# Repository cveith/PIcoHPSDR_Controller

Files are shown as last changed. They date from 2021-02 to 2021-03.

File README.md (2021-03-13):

# PIcoHPSDR Controller

A hardware controller for the piHPSDR application by John Melton, G0ORX.
I've called it PIcoHPSDR Controller, as it's using the newly released Raspberry Pi Pico as an abstraction layer to the hardware.

Inspired by the original controller and therefore parts of this work is based on the original PiHPSDR Controller designed by Kjell Karlsen, LA2NI, et al.
Many thanks Kjell.

## Features
- 1 VFO encoder (5V, open collector outputs)
- 4 Dual Shaft encoders (Alps EC11E type)
- 16 Push Buttons
- PTT, Up, Down, FST Scan from the MH31-A8J microphone
- External PTT, for foot switch
- CW Paddle input
- Audio Out via Headphone or Speaker Output
- Audio In via MH31-A8J Microphone from Yaesu

For more details on piHPSDR, please see https://github.com/g0orx/pihpsdr.

## Protocol Details
The data transmission protocol is pretty straight forward.
Each control element has it's own 7-bit address from Bit 1 through 7.
Bit 0 is reserved for the data portion.

Rotary encoder moves are indicated with value 0 for a counterclockwise step and 1 for a clockwise step.

### Example
PC receives 0b00000010 (Addr: 1, Data: 0):
The main VFO encoder has been turned ccw.

PC receives 0b00000100 (Addr: 2, Data: 1):
The encoder 2 has been turned clock wise.

PC receives 0b00010110 (Addr: 11, Data: 1):
The Encoder 2 Button has been pressed.

PC receives 0b00010110 (Addr: 11, Data: 0):
Encoder 2 Button has been released.

The release state is not used for most switches, but necessary for the external PTT and the Microphone PTT button.

The firmware is split of on a separate repository. Please see https://github.com/cveith/PIcoHPSDR_Controller_Firmware.
Detailed address informations are in a Openoffice Calc file as well.

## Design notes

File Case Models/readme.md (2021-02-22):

# PIcoHPSDR Controller Case Assembly

## Needed Parts

200mm long DSI Connector Cable for connection Pi TFT and Raspberry PI.
3D Printed VFO Dial
17 3d Printed Button Knobs
4 3D printed upper encoder knobs
4 3D printed lower encoder knobs
2 Speakers (CMS-402811-28SP from CUI Devices)

## Two Case models

First Case model uses extruded aluminium profiles as upper and lower case parts.

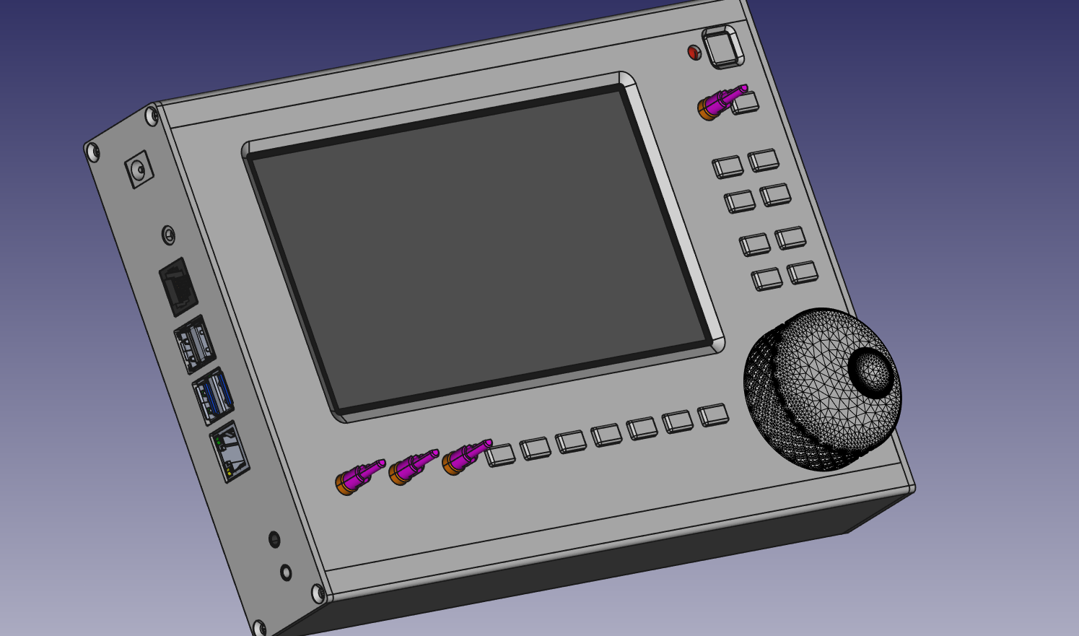
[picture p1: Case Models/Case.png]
Case 1 image


Second model uses bend metal sheets as front and back panel.
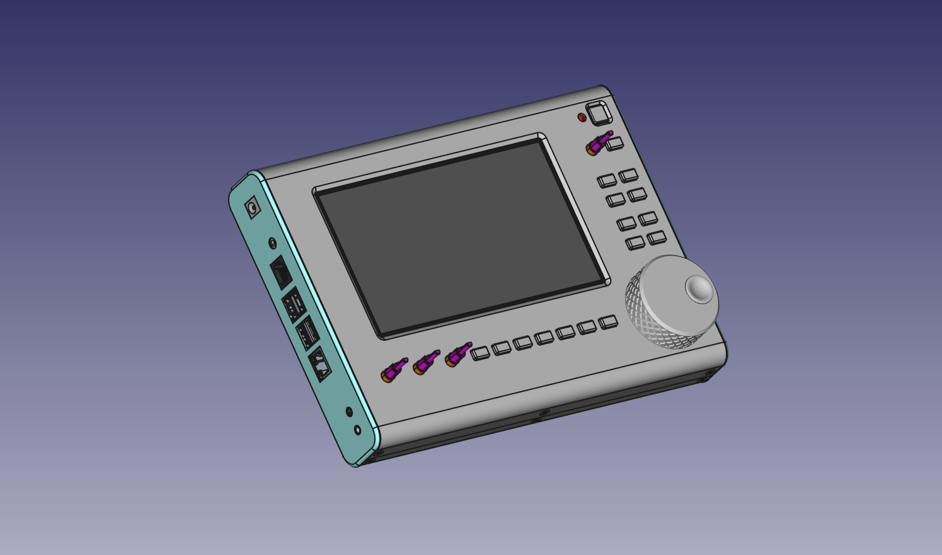
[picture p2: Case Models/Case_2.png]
Case 2 image


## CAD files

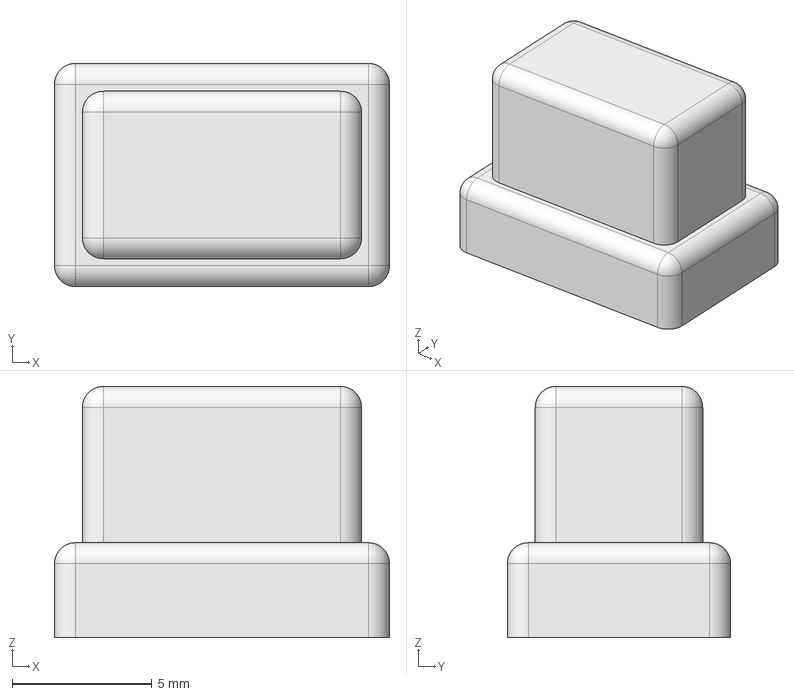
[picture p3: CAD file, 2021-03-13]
Case Models/Button_Cap.FCStd
12.0 x 8.00 x 9.00 mm

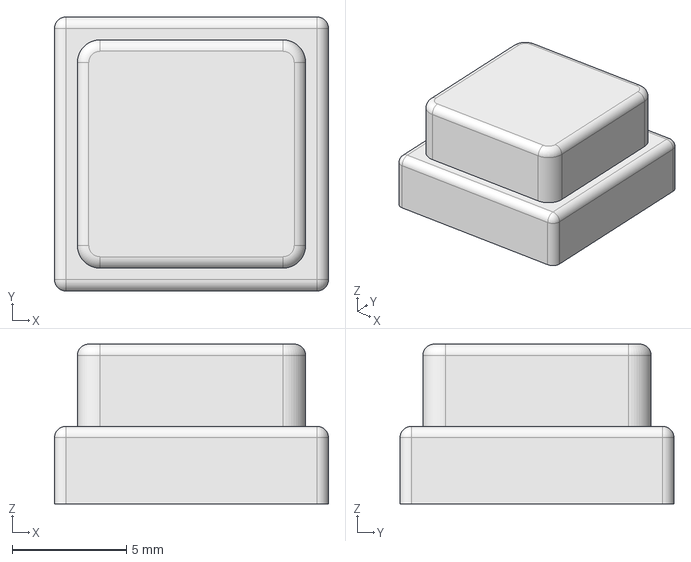
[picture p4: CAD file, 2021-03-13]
Case Models/Button_Cap_Power.FCStd
12.0 x 12.0 x 7.00 mm

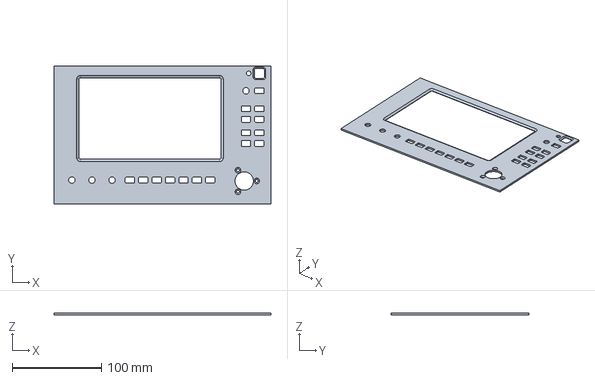
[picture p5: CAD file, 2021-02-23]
Case Models/Front for bent metal sheet.stp
243.0 x 155.0 x 2.00 mm

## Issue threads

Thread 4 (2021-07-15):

Audio Circuit not working

cveith, 2021-07-15:
The audio circuit needs a redesign.
It's only powered from the pi's 3.3V rail which doesn't provide enough power to drive the audio Circuit.

The driver support for that codec is limited.

A Re-Design will take place in the next versions. Propably contain a more "HiFiBerry" compatible solution would be great.

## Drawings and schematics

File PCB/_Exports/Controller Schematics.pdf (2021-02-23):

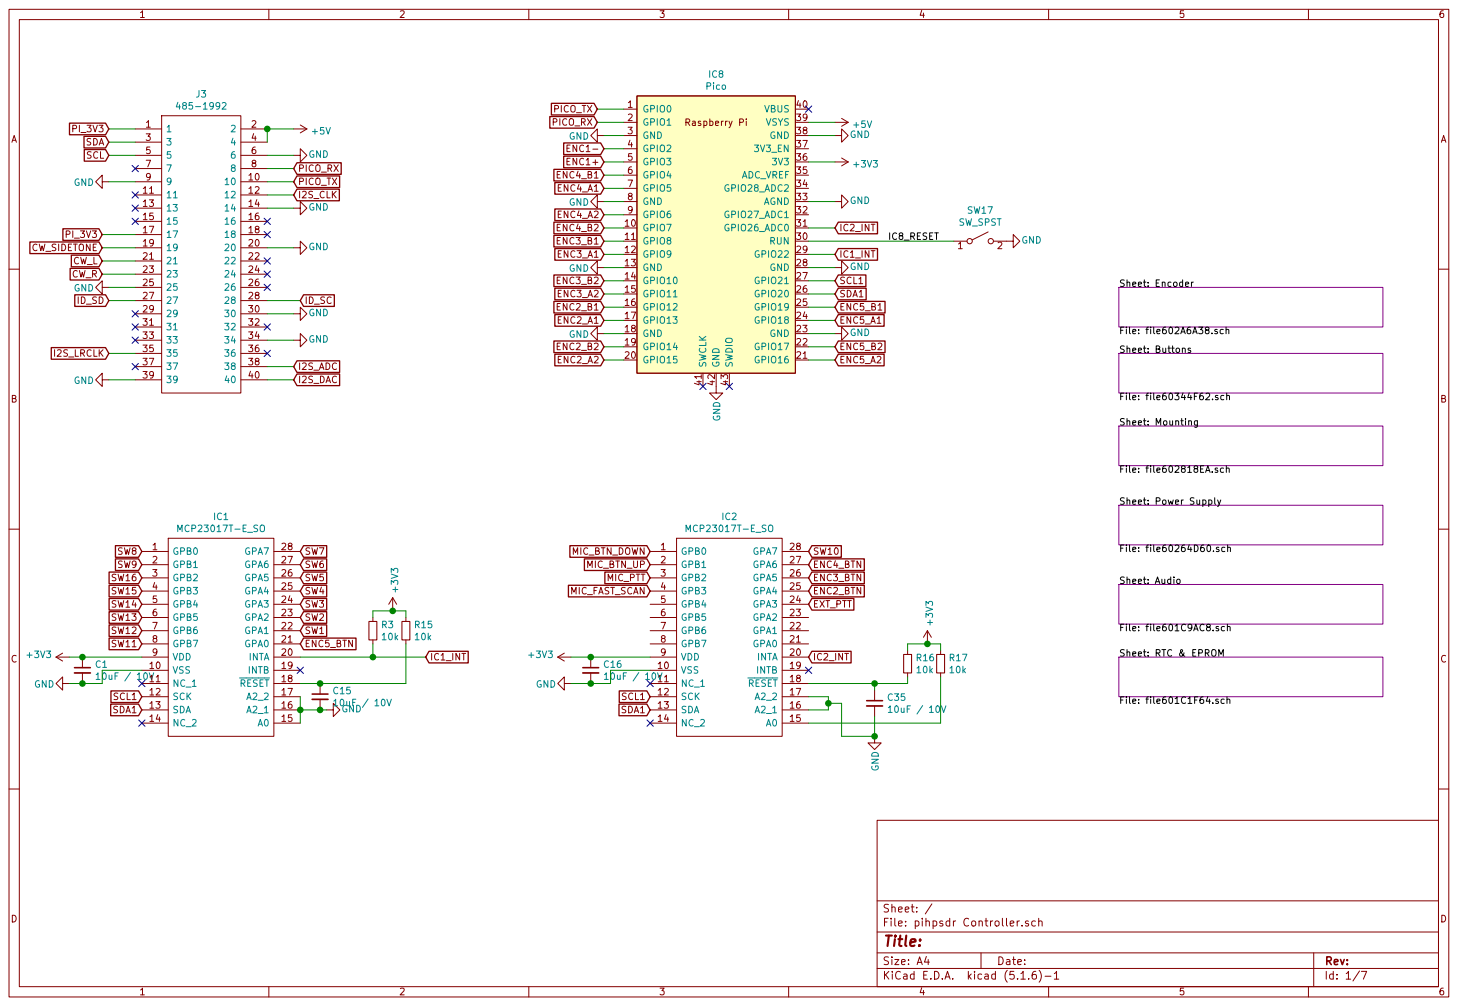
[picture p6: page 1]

Sheet: Encoder File: file602A6A38.sch Sheet: Buttons File: file60344F62.sch Sheet: RTC & EPROM

File: file601C1F64.sch Sheet: Audio File: file601C9AC8.sch Sheet: Mounting File: file602818EA.sch Sheet: Power Supply File: file60264D60.sch C1

File: pihpsdr Controller.sch Sheet: /
Id: 1/7 Title:

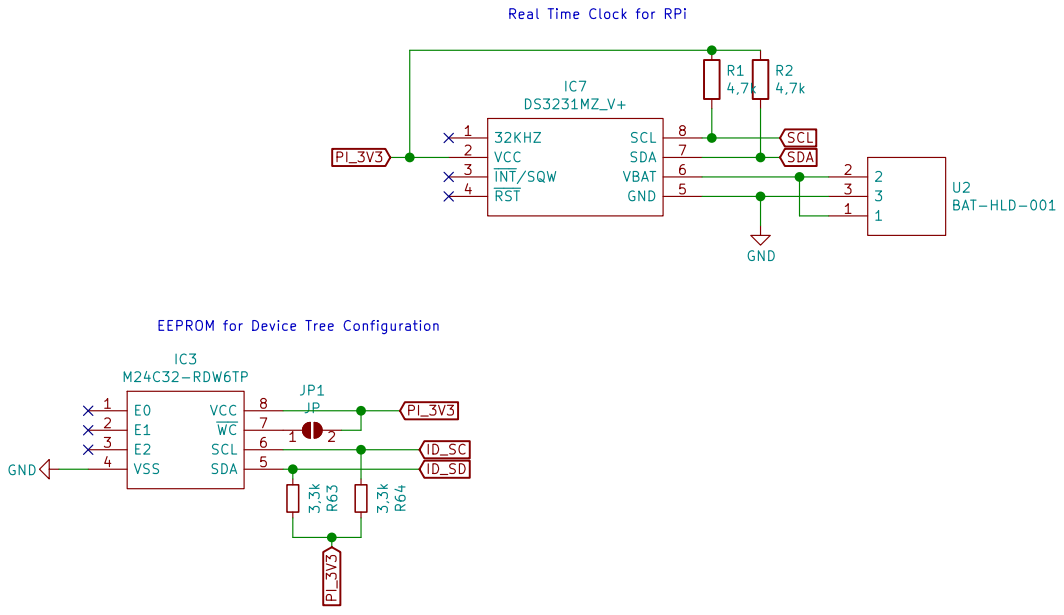
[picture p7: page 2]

Id: 2/7 Title: File: file601C1F64.sch Sheet: /RTC & EPROM/ 3,3k R63

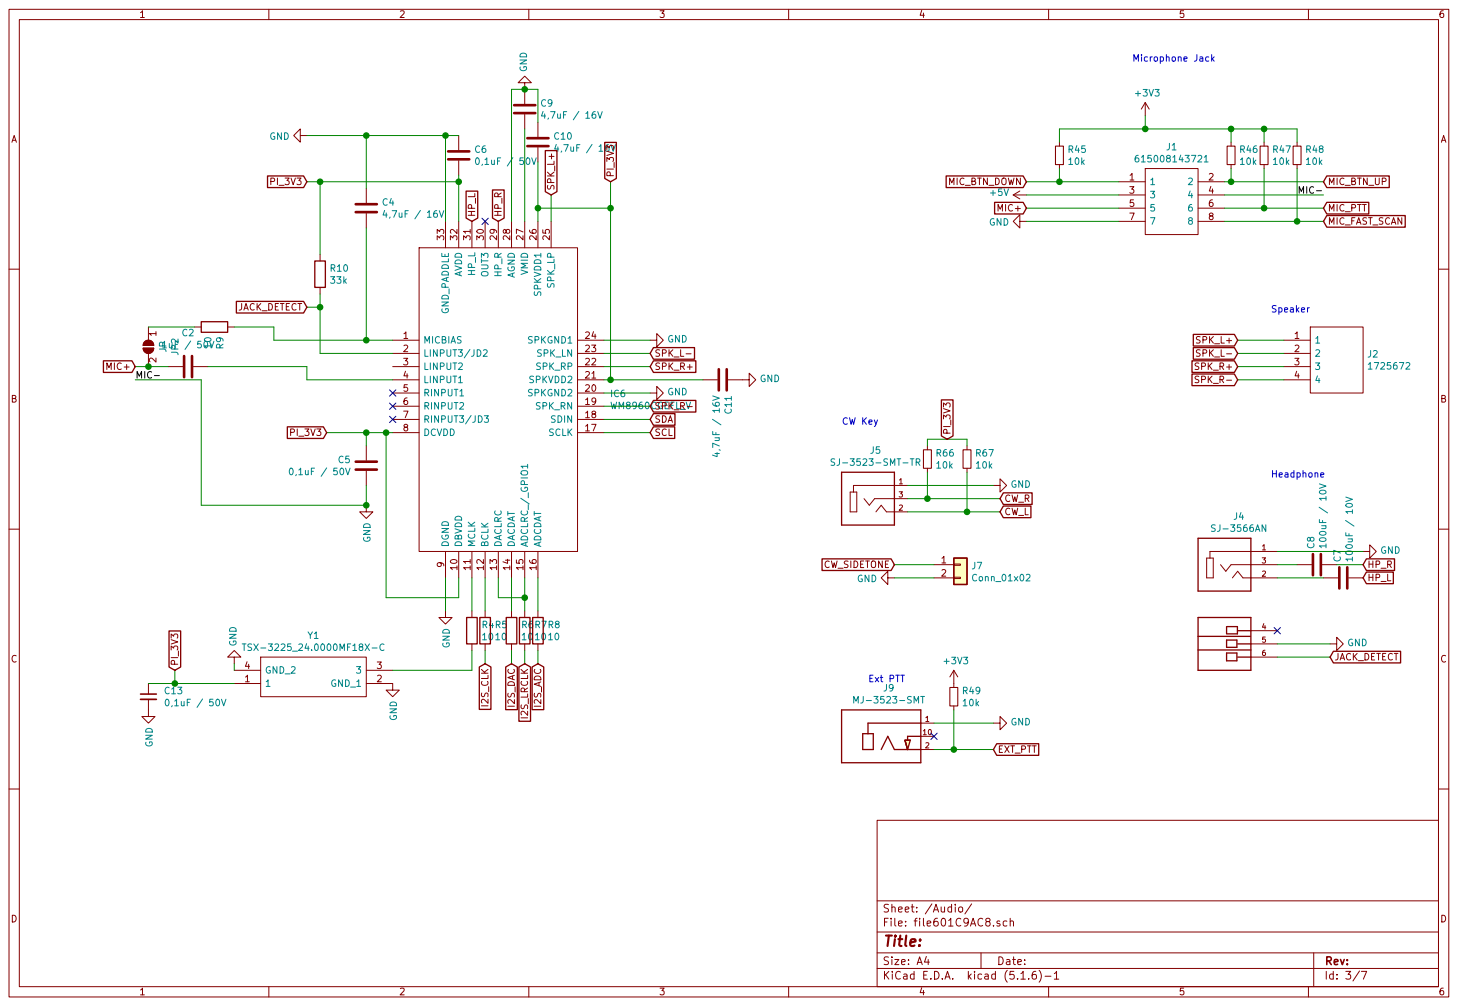
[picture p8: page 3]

Id: 3/7 Title: File: file601C9AC8.sch Sheet: /Audio/ R66

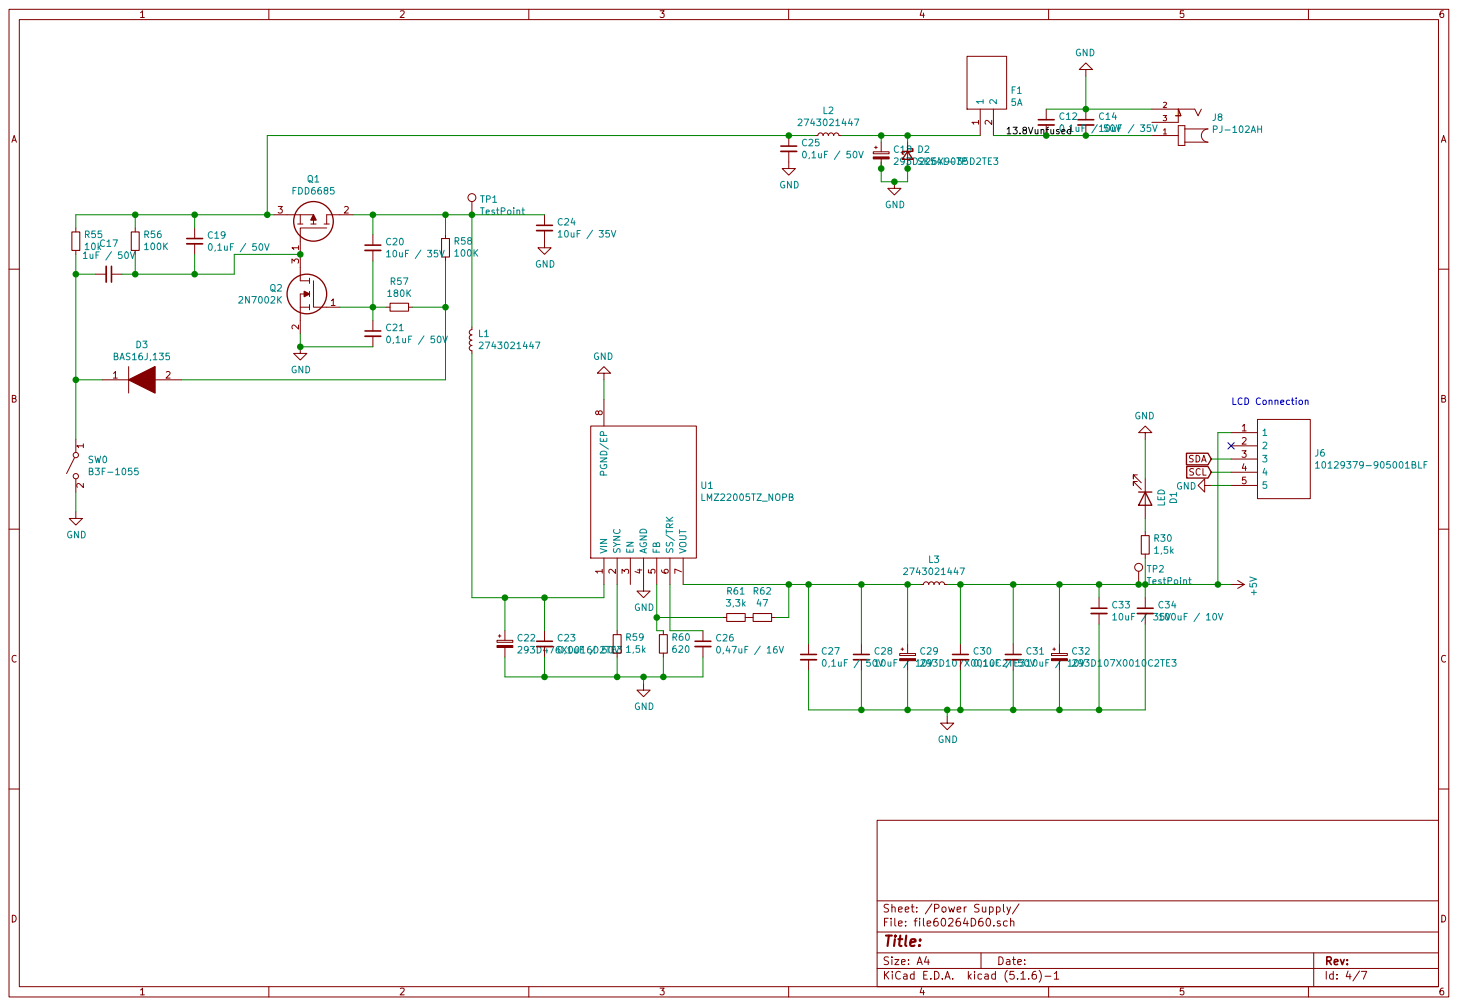
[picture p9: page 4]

Id: 4/7 Title: File: file60264D60.sch Sheet: /Power Supply/ R61

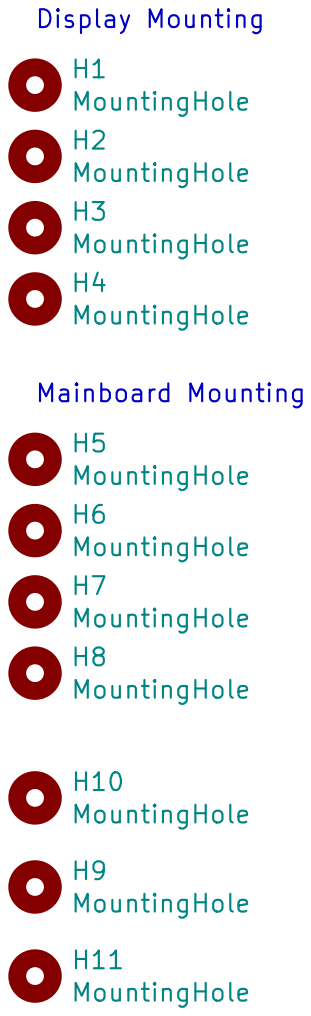
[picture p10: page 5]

Id: 5/7 Title: File: file602818EA.sch Sheet: /Mounting/

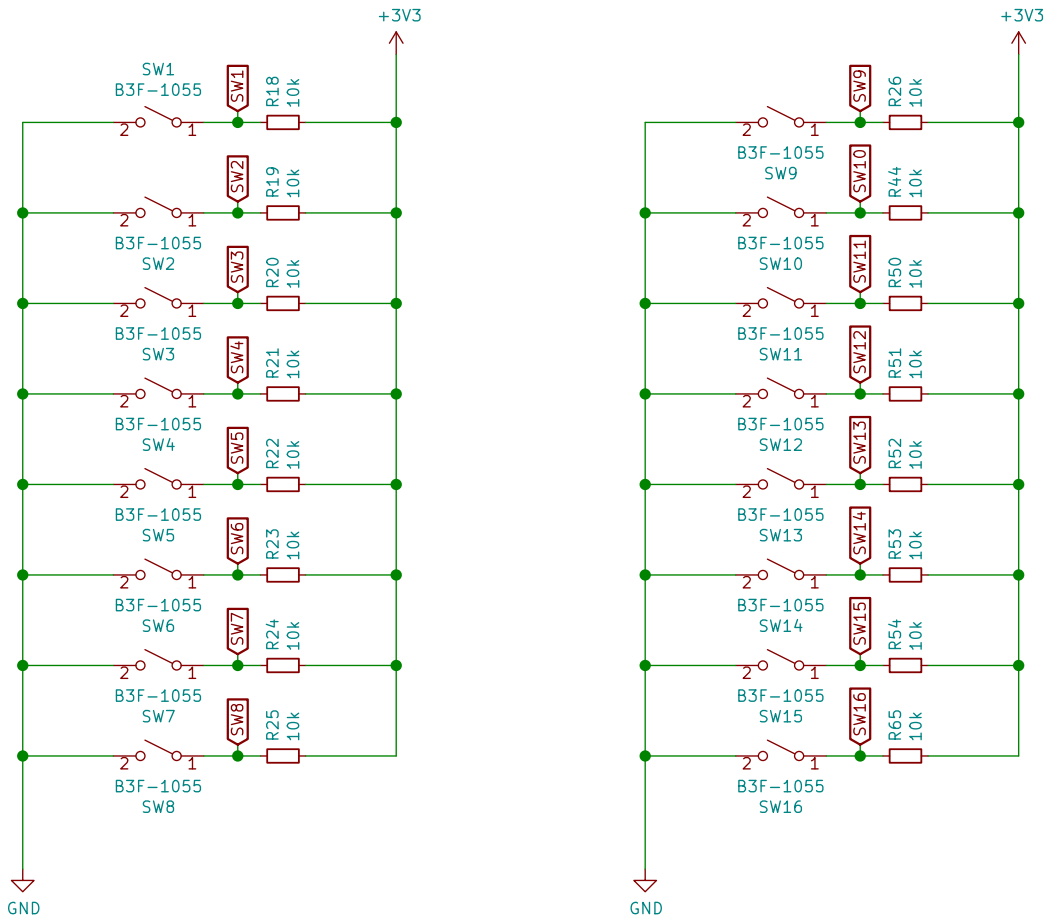
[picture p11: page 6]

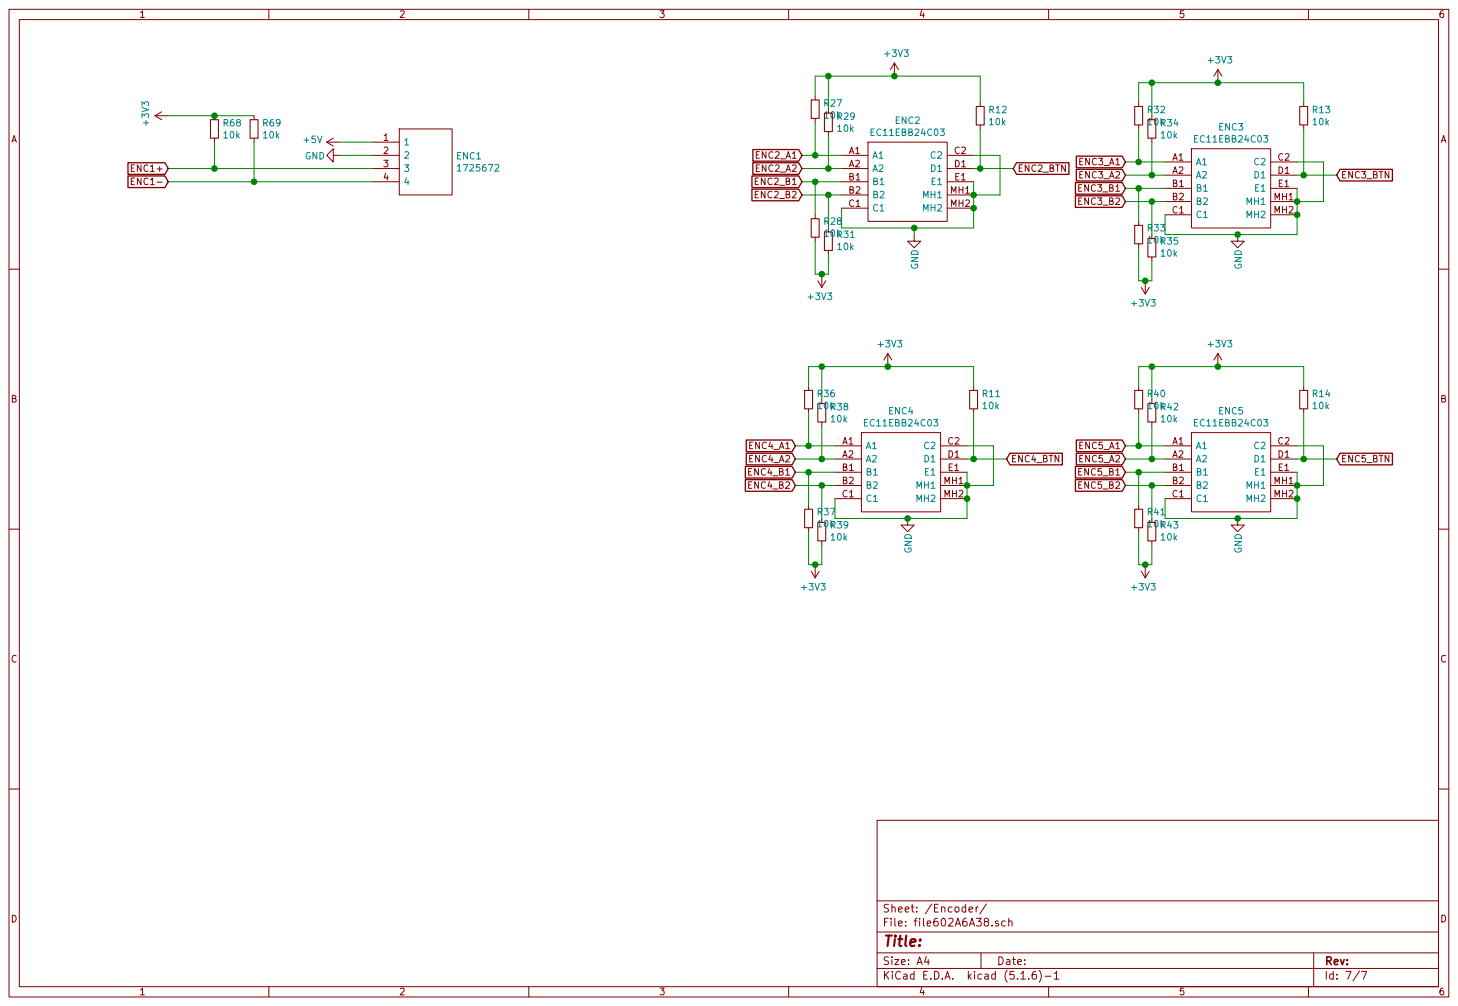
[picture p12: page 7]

Id: 7/7 Title: File: file602A6A38.sch Sheet: /Encoder/

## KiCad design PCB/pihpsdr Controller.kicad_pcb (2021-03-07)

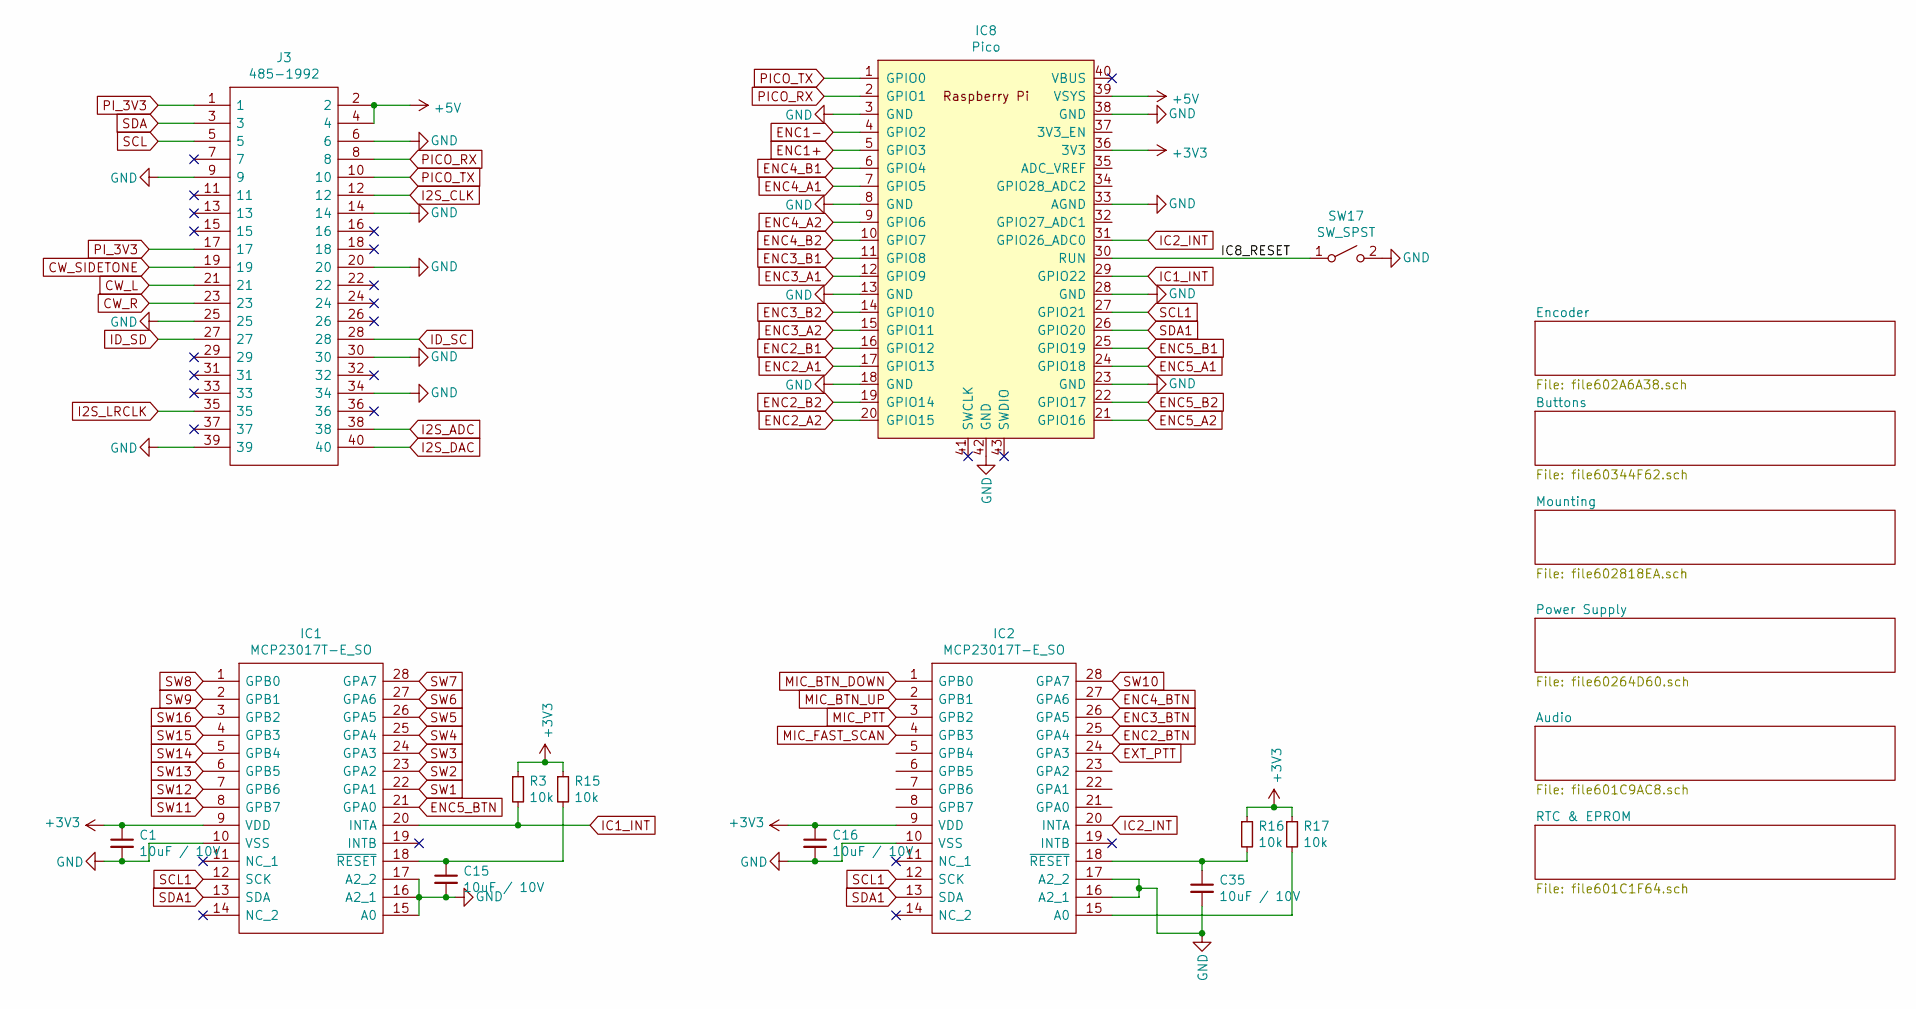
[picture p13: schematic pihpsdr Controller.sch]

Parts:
C1, C15, C16, C35: 10uF / 10V; C_0805_2012Metric_Pad1.15x1.40mm_HandSolder; Manufacturer_Part_Number CL21A106MPFNNNE; LCSC C15850
IC1, IC2: MCP23017T-E_SO; SOIC127P1030X265-28N; Mouser Part Number 579-MCP23017T-E/SO
IC8: Pico; RPi_Pico_SMD_TH; Mouser Part Number 474-DEV-17829
J3: 485-1992; 15445840_PI; Mouser Part Number 485-1992
R3: 10k; R_0805_2012Metric_Pad1.15x1.40mm_HandSolder; Mouser Part Number 71-CRCW080510K0FKEAC
R15, R16, R17: 10k; R_0805_2012Metric_Pad1.15x1.40mm_HandSolder; Manufacturer_Part_Number CRCW080510K0FKEAC; LCSC C17414
SW17: SW_SPST; TL3301SPF260QG; Manufacturer_Part_Number TL3301AF160QG; LCSC C273519

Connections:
+3V3: C1.1, C16.1, IC1.9 (VDD), IC2.9 (VDD), IC8.36 (3V3), R3.1, R15.1, R16.1, R17.1; also elsewhere on the board
+5V: IC8.39 (VSYS), J3.2, J3.4; also elsewhere on the board
/IC8_RESET: IC8.30 (RUN), SW17.1 (A)
CW_L: J3.21; also elsewhere on the board
CW_R: J3.23; also elsewhere on the board
CW_SIDETONE: J3.19; also elsewhere on the board
ENC1+: IC8.5 (GPIO3); also elsewhere on the board
ENC1-: IC8.4 (GPIO2); also elsewhere on the board
ENC2_A1: IC8.17 (GPIO13); also elsewhere on the board
ENC2_A2: IC8.20 (GPIO15); also elsewhere on the board
ENC2_B1: IC8.16 (GPIO12); also elsewhere on the board
ENC2_B2: IC8.19 (GPIO14); also elsewhere on the board
ENC2_BTN: IC2.25 (GPA4); also elsewhere on the board
ENC3_A1: IC8.12 (GPIO9); also elsewhere on the board
ENC3_A2: IC8.15 (GPIO11); also elsewhere on the board
ENC3_B1: IC8.11 (GPIO8); also elsewhere on the board
ENC3_B2: IC8.14 (GPIO10); also elsewhere on the board
ENC3_BTN: IC2.26 (GPA5); also elsewhere on the board
ENC4_A1: IC8.7 (GPIO5); also elsewhere on the board
ENC4_A2: IC8.9 (GPIO6); also elsewhere on the board
ENC4_B1: IC8.6 (GPIO4); also elsewhere on the board
ENC4_B2: IC8.10 (GPIO7); also elsewhere on the board
ENC4_BTN: IC2.27 (GPA6); also elsewhere on the board
ENC5_A1: IC8.24 (GPIO18); also elsewhere on the board
ENC5_A2: IC8.21 (GPIO16); also elsewhere on the board
ENC5_B1: IC8.25 (GPIO19); also elsewhere on the board
ENC5_B2: IC8.22 (GPIO17); also elsewhere on the board
ENC5_BTN: IC1.21 (GPA0); also elsewhere on the board
EXT_PTT: IC2.24 (GPA3); also elsewhere on the board
GND: C1.2, C15.2, C16.2, C35.2, IC1.10 (VSS), IC1.15 (A0), IC1.16 (A2_1), IC1.17 (A2_2), IC2.10 (VSS), IC2.16 (A2_1), IC2.17 (A2_2), IC8.3 (GND), IC8.8 (GND), IC8.13 (GND), IC8.18 (GND), IC8.23 (GND), IC8.28 (GND), IC8.33 (AGND), IC8.38 (GND), IC8.42 (GND), J3.6, J3.9, J3.14, J3.20, J3.25, J3.30, J3.34, J3.39, SW17.2 (B); also elsewhere on the board
I2S_ADC: J3.38; also elsewhere on the board
I2S_CLK: J3.12; also elsewhere on the board
I2S_DAC: J3.40; also elsewhere on the board
I2S_LRCLK: J3.35; also elsewhere on the board
IC1_INT: IC1.20 (INTA), IC8.29 (GPIO22), R3.2
IC2_INT: IC2.20 (INTA), IC8.31 (GPIO26_ADC0)
ID_SC: J3.28; also elsewhere on the board
ID_SD: J3.27; also elsewhere on the board
MIC_BTN_DOWN: IC2.1 (GPB0); also elsewhere on the board
MIC_BTN_UP: IC2.2 (GPB1); also elsewhere on the board
MIC_FAST_SCAN: IC2.4 (GPB3); also elsewhere on the board
MIC_PTT: IC2.3 (GPB2); also elsewhere on the board
unnamed: C15.1, IC1.18 (~RESET), R15.2
unnamed: C35.1, IC2.18 (~RESET), R16.2
unnamed: IC2.15 (A0), R17.2
PICO_RX: IC8.2 (GPIO1), J3.8
PICO_TX: IC8.1 (GPIO0), J3.10
PI_3V3: J3.1, J3.17; also elsewhere on the board
SCL: J3.5; also elsewhere on the board
SCL1: IC1.12 (SCK), IC2.12 (SCK), IC8.27 (GPIO21)
SDA: J3.3; also elsewhere on the board
SDA1: IC1.13 (SDA), IC2.13 (SDA), IC8.26 (GPIO20)
SW1: IC1.22 (GPA1); also elsewhere on the board
SW2: IC1.23 (GPA2); also elsewhere on the board
SW3: IC1.24 (GPA3); also elsewhere on the board
SW4: IC1.25 (GPA4); also elsewhere on the board
SW5: IC1.26 (GPA5); also elsewhere on the board
SW6: IC1.27 (GPA6); also elsewhere on the board
SW7: IC1.28 (GPA7); also elsewhere on the board
SW8: IC1.1 (GPB0); also elsewhere on the board
SW9: IC1.2 (GPB1); also elsewhere on the board
SW10: IC2.28 (GPA7); also elsewhere on the board
SW11: IC1.8 (GPB7); also elsewhere on the board
SW12: IC1.7 (GPB6); also elsewhere on the board
SW13: IC1.6 (GPB5); also elsewhere on the board
SW14: IC1.5 (GPB4); also elsewhere on the board
SW15: IC1.4 (GPB3); also elsewhere on the board
SW16: IC1.3 (GPB2); also elsewhere on the board

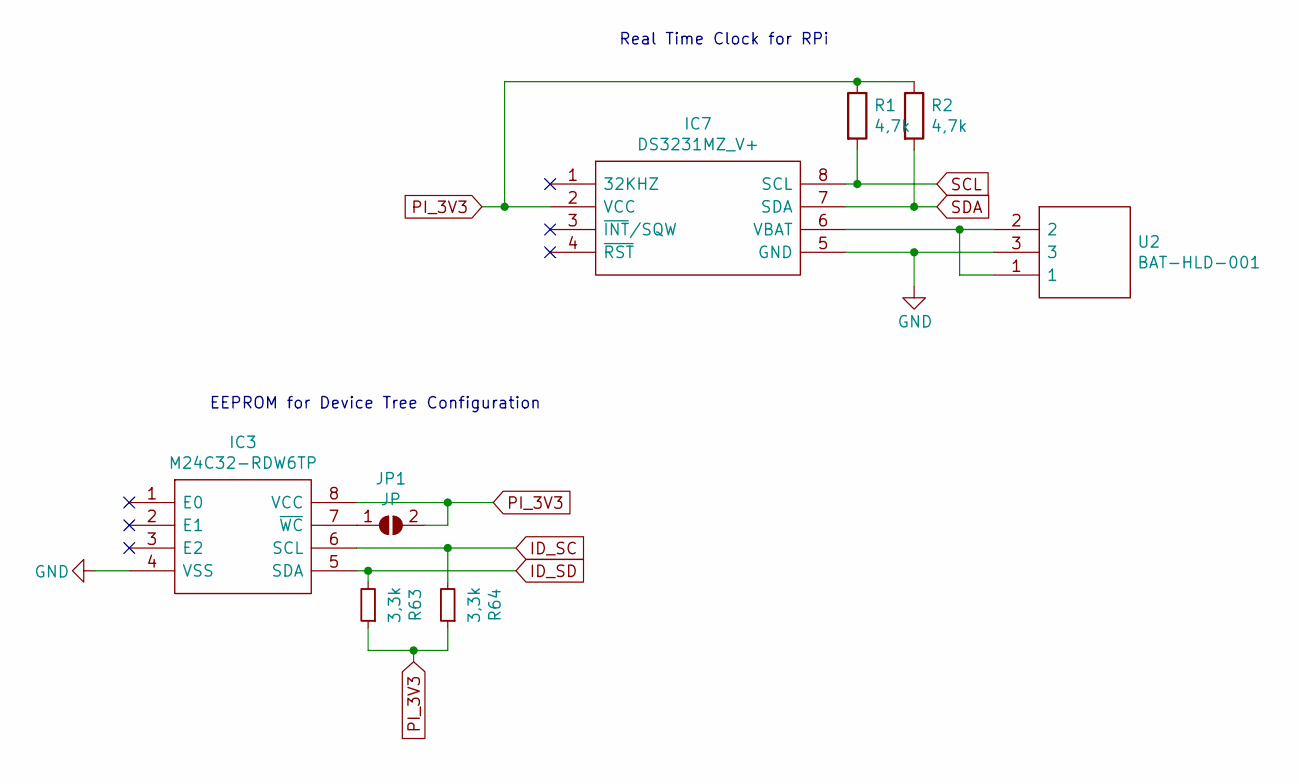
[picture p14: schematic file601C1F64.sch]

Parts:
IC3: M24C32-RDW6TP; SOP65P640X120-8N; Mouser Part Number 511-M24C32-RDW6TP
IC7: DS3231MZ_V+; SOIC127P600X175-8N; Mouser Part Number 700-DS3231MZ/V+
JP1: JP; SolderJumper-2_P1.3mm_Open_RoundedPad1.0x1.5mm
R1, R2: 4,7k; R_0805_2012Metric_Pad1.15x1.40mm_HandSolder; Manufacturer_Part_Number CRCW08054K70FKEAC; LCSC C17673
R63, R64: 3,3k; R_0805_2012Metric_Pad1.15x1.40mm_HandSolder; Manufacturer_Part_Number CRCW08053K30FKEAC; LCSC C26010
U2: BAT-HLD-001; BATHLD001; Mouser Part Number 712-BAT-HLD-001

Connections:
GND: IC3.4 (VSS), IC7.5 (GND), U2.3; also elsewhere on the board
ID_SC: IC3.6 (SCL), R64.2; also elsewhere on the board
ID_SD: IC3.5 (SDA), R63.2; also elsewhere on the board
unnamed: IC3.7 (~WC), JP1.1 (A)
unnamed: IC7.6 (VBAT), U2.1, U2.2
PI_3V3: IC3.8 (VCC), IC7.2 (VCC), JP1.2 (B), R1.1, R2.1, R63.1, R64.1; also elsewhere on the board
SCL: IC7.8 (SCL), R1.2; also elsewhere on the board
SDA: IC7.7 (SDA), R2.2; also elsewhere on the board

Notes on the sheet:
EEPROM for Device Tree Configuration
Real Time Clock for RPi

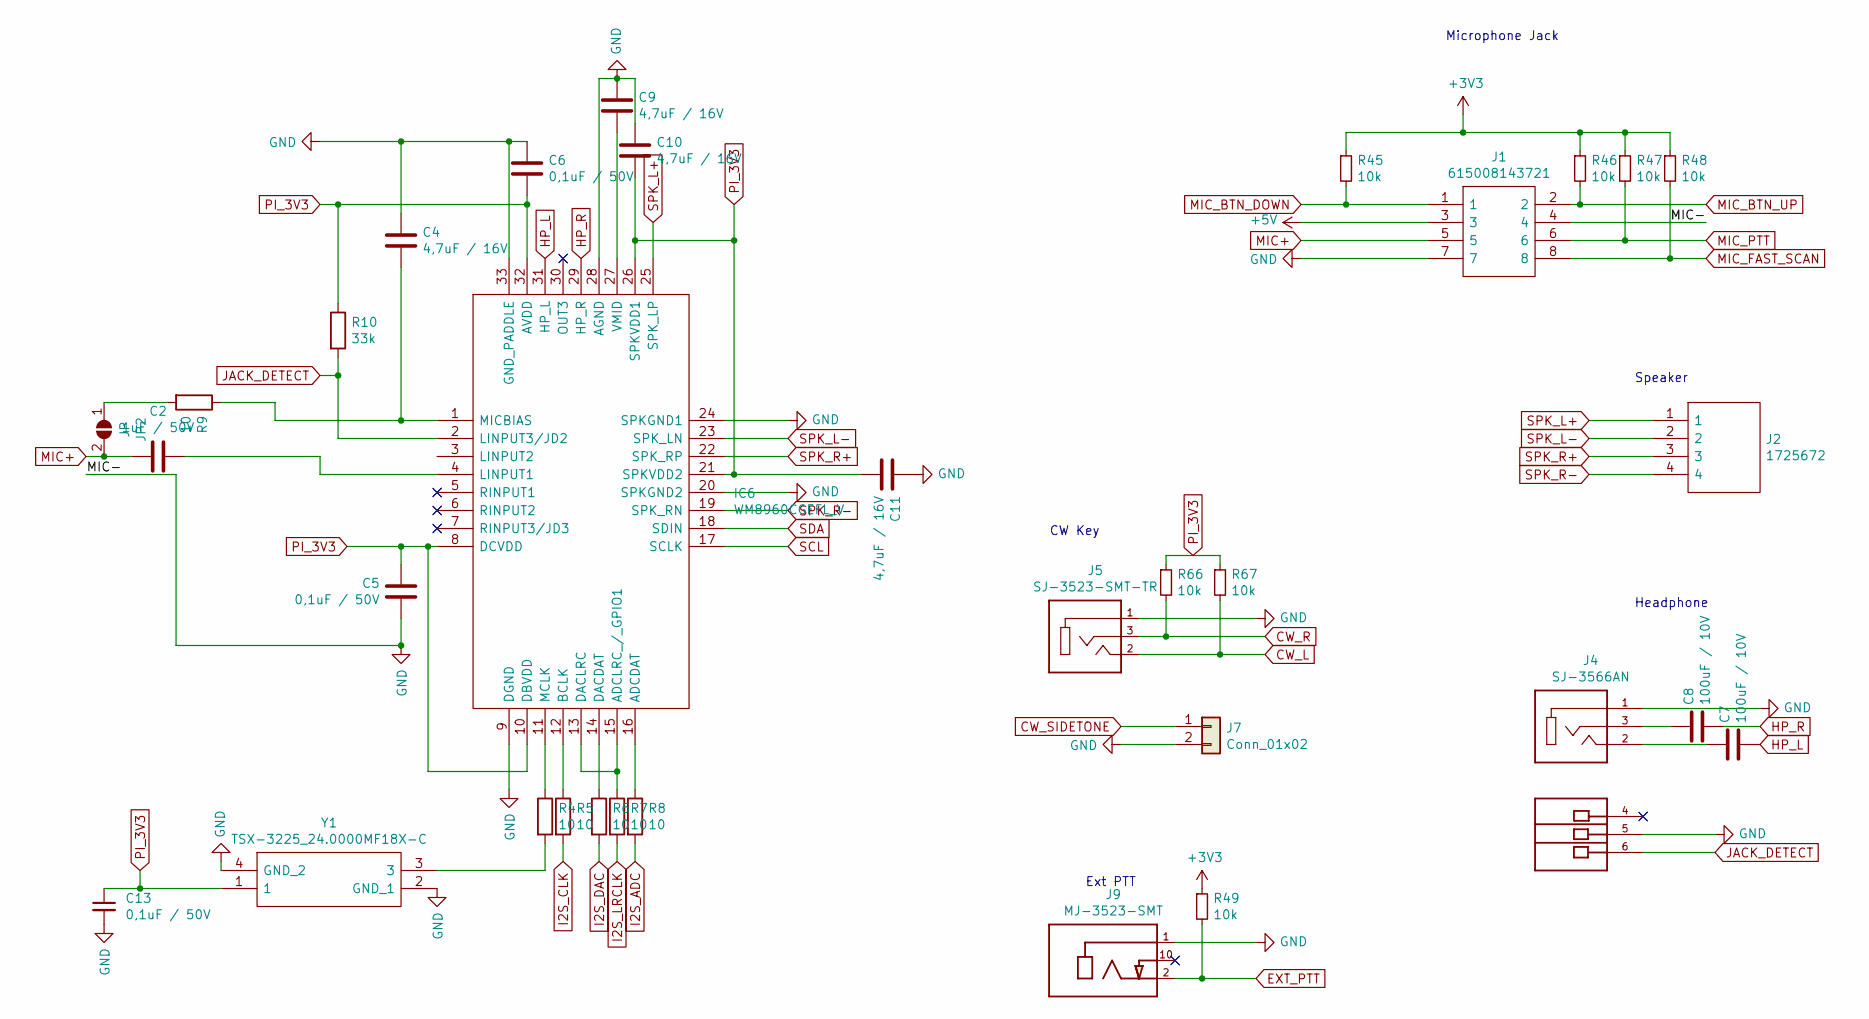
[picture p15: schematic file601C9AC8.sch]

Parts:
C2: 1uF / 50V; C_0805_2012Metric_Pad1.15x1.40mm_HandSolder; Manufacturer_Part_Number CL21B105KBFNNNE; LCSC C28323
C4, C9, C10, C11: 4,7uF / 16V; C_0805_2012Metric_Pad1.15x1.40mm_HandSolder; Manufacturer_Part_Number CL21A475KOFNNNE; LCSC C1779
C5, C6, C13: 0,1uF / 50V; C_0805_2012Metric_Pad1.15x1.40mm_HandSolder; Manufacturer_Part_Number CL21B104KBCSFNC; LCSC C49678
C7, C8: 100uF / 10V; C_1206_3216Metric_Pad1.42x1.75mm_HandSolder; Manufacturer_Part_Number GRM32ER61A107ME20L; LCSC C84455
IC6: WM8960CGEFL_V; CUST_QFN-32-1EP_5x5mm_P0.5mm_EP3.45x3.45mm; Mouser Part Number 238-WM8960CGEFL/V
J1: 615008143721; Mouser Part Number 710-615008143721
J2: 1725672; 1725672-4-2.54; Mouser Part Number 651-1725672
J4: SJ-3566AN; CUI_SJ-3566AN; Manufacturer_Part_Number SJ-3566AN; Mouser Part Number 490-SJ-3566AN
J5: SJ-3523-SMT-TR; CUI_SJ-3523-SMT-TR; Manufacturer_Part_Number SJ-3523-SMT-TR; Mouser Part Number 490-SJ-3523-SMT-TR
J7: Conn_01x02; PinHeader_1x02_P2.54mm_Horizontal; Manufacturer_Part_Number 10129379-902001BLF; Mouser Part Number 649-1012937990201BLF
J9: MJ-3523-SMT; CUI_MJ-3523-SMT; PART_REV D; Mouser Part Number 490-MJ-3523-SMT-TR
JP2: JP; SolderJumper-2_P1.3mm_Open_RoundedPad1.0x1.5mm
R4, R5, R6, R7, R8, R9: 10; R_0805_2012Metric_Pad1.15x1.40mm_HandSolder; Manufacturer_Part_Number CRCW080510R0FKEB; LCSC C17415
R10: 33k; R_0805_2012Metric_Pad1.15x1.40mm_HandSolder; Manufacturer_Part_Number CRCW080533K0FKEA; LCSC C17633
R45, R46, R47, R48, R49, R66, R67: 10k; R_0805_2012Metric_Pad1.15x1.40mm_HandSolder; Manufacturer_Part_Number CRCW080510K0FKEAC; LCSC C17414
Y1: TSX-3225_24.0000MF18X-C; TSX3225160000MF18XAC0; Mouser Part Number 732-TSX-32224MF18X-C

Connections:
+3V3: R45.1, R46.1, R47.1, R48.1, R49.1; also elsewhere on the board
+5V: J1.3; also elsewhere on the board
CW_L: J5.2, R67.2; also elsewhere on the board
CW_R: J5.3, R66.2; also elsewhere on the board
CW_SIDETONE: J7.1; also elsewhere on the board
EXT_PTT: J9.2, R49.2; also elsewhere on the board
GND: C4.1, C5.2, C6.1, C9.1, C10.1, C11.1, C13.2, IC6.9 (DGND), IC6.20 (SPKGND2), IC6.24 (SPKGND1), IC6.28 (AGND), IC6.33 (GND_PADDLE), J1.4, J1.7, J4.1, J4.5, J5.1, J7.2, J9.1, Y1.2 (GND_1), Y1.4 (GND_2); also elsewhere on the board
HP_L: C7.2, IC6.31 (HP_L)
HP_R: C8.2, IC6.29 (HP_R)
I2S_ADC: R8.2; also elsewhere on the board
I2S_CLK: R5.2; also elsewhere on the board
I2S_DAC: R6.2; also elsewhere on the board
I2S_LRCLK: R7.2; also elsewhere on the board
JACK_DETECT: IC6.2 (LINPUT3/JD2), J4.6, R10.2
MIC+: C2.1, J1.5, JP2.2 (B)
MIC_BTN_DOWN: J1.1, R45.2; also elsewhere on the board
MIC_BTN_UP: J1.2, R46.2; also elsewhere on the board
MIC_FAST_SCAN: J1.8, R48.2; also elsewhere on the board
MIC_PTT: J1.6, R47.2; also elsewhere on the board
unnamed: C2.2, IC6.4 (LINPUT1)
unnamed: C4.2, IC6.1 (MICBIAS), R9.1
unnamed: C7.1, J4.2
unnamed: C8.1, J4.3
unnamed: C9.2, IC6.27 (VMID)
unnamed: IC6.11 (MCLK), R4.1
unnamed: IC6.12 (BCLK), R5.1
unnamed: IC6.13 (DACLRC), IC6.15 (ADCLRC_/_GPIO1), R7.1
unnamed: IC6.14 (DACDAT), R6.1
unnamed: IC6.16 (ADCDAT), R8.1
unnamed: JP2.1 (A), R9.2
unnamed: R4.2, Y1.3
PI_3V3: C5.1, C6.2, C10.2, C11.2, C13.1, IC6.8 (DCVDD), IC6.10 (DBVDD), IC6.21 (SPKVDD2), IC6.26 (SPKVDD1), IC6.32 (AVDD), R10.1, R66.1, R67.1, Y1.1; also elsewhere on the board
SCL: IC6.17 (SCLK); also elsewhere on the board
SDA: IC6.18 (SDIN); also elsewhere on the board
SPK_L+: IC6.25 (SPK_LP), J2.1
SPK_L-: IC6.23 (SPK_LN), J2.2
SPK_R+: IC6.22 (SPK_RP), J2.3
SPK_R-: IC6.19 (SPK_RN), J2.4

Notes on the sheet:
Headphone
Speaker
Microphone Jack
Ext PTT
CW Key

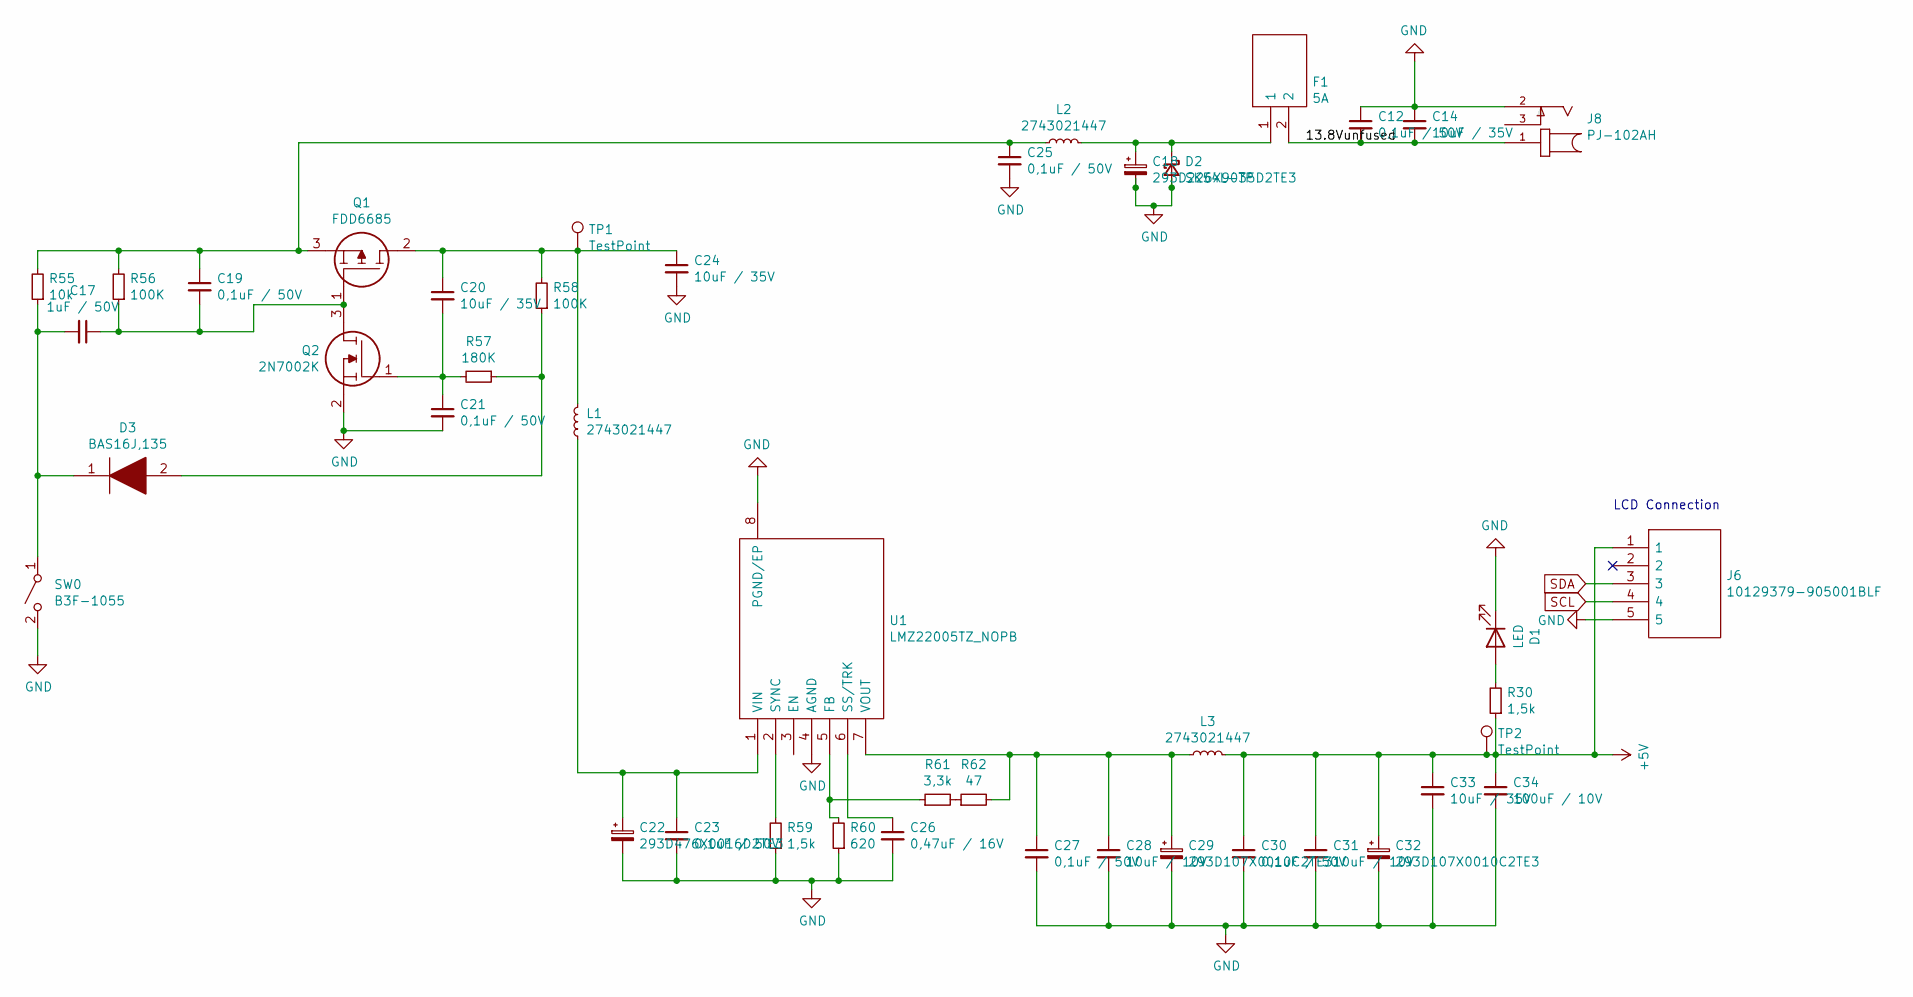
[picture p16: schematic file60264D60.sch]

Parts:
C12, C19, C21, C23, C25, C27, C30: 0,1uF / 50V; C_0805_2012Metric_Pad1.15x1.40mm_HandSolder; Manufacturer_Part_Number CL21B104KBCSFNC; LCSC C49678
C14, C20, C24, C33: 10uF / 35V; C_0805_2012Metric_Pad1.15x1.40mm_HandSolder; Manufacturer_Part_Number CL21A106KAYNNNE; Mouser Part Number 187-CL21A106KAYNNNE
C17: 1uF / 50V; C_0805_2012Metric_Pad1.15x1.40mm_HandSolder; Manufacturer_Part_Number CL21B105KBFNNNE; LCSC C28323
C18: 293D226X9035D2TE3; CAPPM7343X310N; Mouser Part Number 74-293D226X9035D2TE3
C22: 293D476X0016D2TE3; CAPPM7343X310N; Mouser Part Number 74-293D476X0016D2TE3
C26: 0,47uF / 16V; C_0805_2012Metric_Pad1.15x1.40mm_HandSolder; Manufacturer_Part_Number CL21B474KBFNNNE; Mouser Part Number 187-CL21B474KBFNNNE
C28, C31: 10uF / 10V; C_0805_2012Metric_Pad1.15x1.40mm_HandSolder; Manufacturer_Part_Number CL21A106MPFNNNE; LCSC C15850
C29, C32: 293D107X0010C2TE3; CAPPM6032X280N; Mouser Part Number 74-293D107X0010C2TE3
C34: 100uF / 10V; C_1206_3216Metric_Pad1.42x1.75mm_HandSolder; Manufacturer_Part_Number GRM32ER61A107ME20L; LCSC C84455
D1: LED; LED_D5.0mm
D2: SK54L-TP; DIOM7959X262N; Mouser Part Number 833-SK54L-TP
D3: BAS16J,135; SODFL2512X80N; Mouser Part Number 771-BAS16J135
F1: 5A; 65600001009; Mouser Part Number 576-65600001009
J6: 10129379-905001BLF; HDRRA5W67P0X254_1X5_1270X254X241P; Mouser Part Number 649-1012937990501BLF
J8: PJ-102AH; CUI_PJ-102AH; PART_REV 1.02; Mouser Part Number 490-PJ-102AH
L1, L2, L3: 2743021447; Mouser Part Number 623-2743021447LF
Q1: FDD6685; FQD1N80TM; Mouser Part Number 512-FDD6685
Q2: 2N7002K; SOT95P240X120-3N; Mouser Part Number 512-2N7002K
R30, R59: 1,5k; R_0805_2012Metric_Pad1.15x1.40mm_HandSolder; Manufacturer_Part_Number CRCW08051K50FKEA; LCSC C4310
R55: 10k; R_0805_2012Metric_Pad1.15x1.40mm_HandSolder; Manufacturer_Part_Number CRCW080510K0FKEAC; LCSC C17414
R56, R58: 100K; R_0805_2012Metric_Pad1.15x1.40mm_HandSolder; Manufacturer_Part_Number CRCW0805100KFKEAC; LCSC C17407
R57: 180K; R_0805_2012Metric_Pad1.15x1.40mm_HandSolder; Manufacturer_Part_Number CRCW0805180KFKEAC; LCSC C17501
R60: 620; R_0805_2012Metric_Pad1.15x1.40mm_HandSolder; Manufacturer_Part_Number CRCW0805620RFKEA; LCSC C23220
R61: 3,3k; R_0805_2012Metric_Pad1.15x1.40mm_HandSolder; Manufacturer_Part_Number CRCW08053K30FKEAC; LCSC C26010
R62: 47; R_0805_2012Metric_Pad1.15x1.40mm_HandSolder; Manufacturer_Part_Number CRCW080547R0FKEAC; LCSC C17714
SW0: B3F-1055; B3F1000; Mouser Part Number 653-B3F-1055
TP1, TP2: TestPoint; TestPoint_Pad_D3.0mm
U1: LMZ22005TZ_NOPB; NDW0007A; Mouser Part Number 926-LMZ22005TZ/NOPB

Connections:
+5V: C30.1, C31.1, C32.1, C33.1, C34.1, J6.1, L3.2, R30.1, TP2.1; also elsewhere on the board
/Power Supply/13.8Vunfused: C12.2, C14.2, F1.2, J8.1
GND: C12.1, C14.1, C18.2, C21.2, C22.2, C23.2, C24.2, C25.2, C26.2, C27.2, C28.2, C29.2, C30.2, C31.2, C32.2, C33.2, C34.2, D1.1 (K), D2.2 (A), J6.5, J8.2, Q2.2, R59.1, R60.1, SW0.2 (B), U1.4 (AGND), U1.8 (PGND/EP); also elsewhere on the board
unnamed: C17.1, C19.2, Q1.1, Q2.3, R56.1
unnamed: C17.2, D3.1, R55.1, SW0.1 (A)
unnamed: C18.1, D2.1 (K), F1.1, L2.2
unnamed: C19.1, C25.1, L2.1, Q1.3, R55.2, R56.2
unnamed: C20.1, C24.1, L1.2, Q1.2, R58.2, TP1.1
unnamed: C20.2, C21.1, Q2.1, R57.2
unnamed: C22.1, C23.1, L1.1, U1.1 (VIN)
unnamed: C26.1, U1.6 (SS/TRK)
unnamed: C27.1, C28.1, C29.1, L3.1, R62.2, U1.7 (VOUT)
unnamed: D1.2 (A), R30.2
unnamed: D3.2, R57.1, R58.1
unnamed: R59.2, U1.2 (SYNC)
unnamed: R60.2, R61.1, U1.5 (FB)
unnamed: R61.2, R62.1
SCL: J6.4; also elsewhere on the board
SDA: J6.3; also elsewhere on the board

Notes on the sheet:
LCD Connection

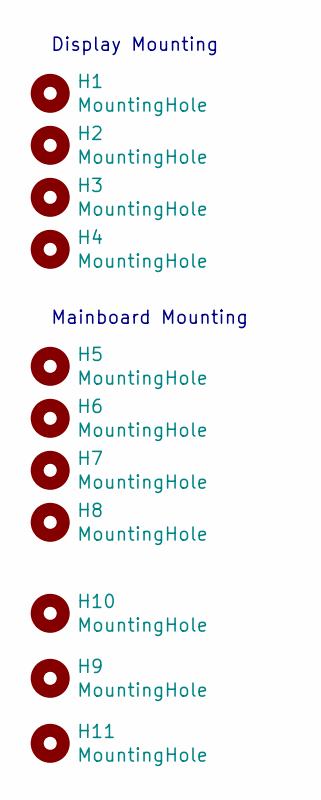
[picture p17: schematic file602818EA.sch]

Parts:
H1, H2, H3, H4: MountingHole; MountingHole_3.5mm_Pad
H5, H6, H7, H8, H9, H10, H11: MountingHole; MountingHole_3.2mm_M3_DIN965_Pad

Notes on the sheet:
Mainboard Mounting
Display Mounting

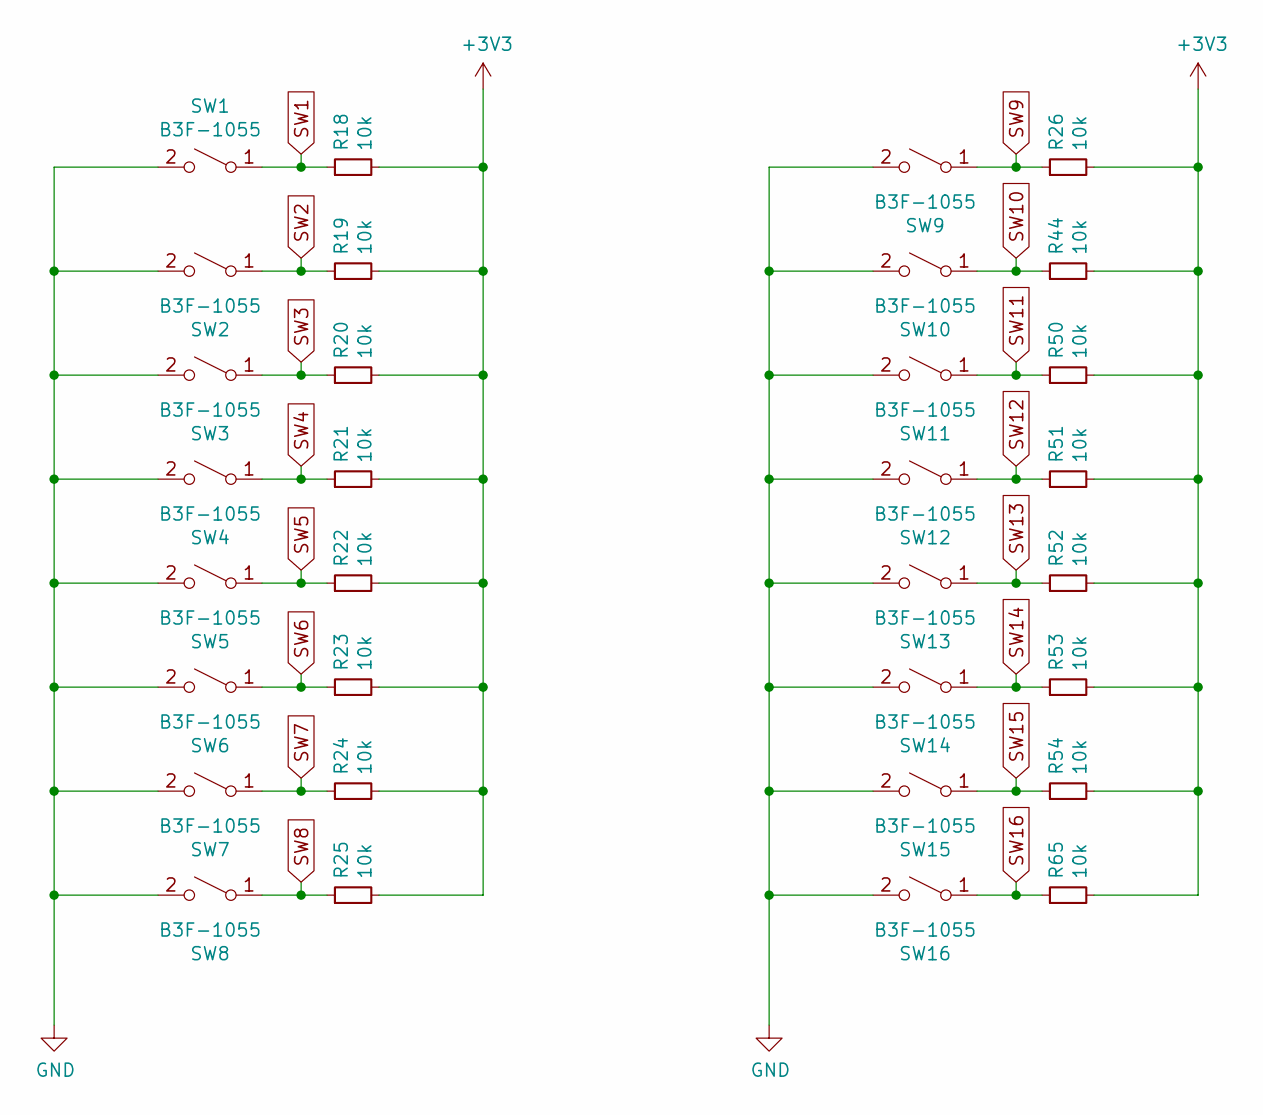
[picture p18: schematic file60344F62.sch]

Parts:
R18, R19, R20, R21, R22, R23, R24, R25, R26, R44, R50, R51, R52, R53, R54, R65: 10k; R_0805_2012Metric_Pad1.15x1.40mm_HandSolder; Manufacturer_Part_Number CRCW080510K0FKEAC; LCSC C17414
SW1, SW2, SW3, SW4, SW5, SW6, SW7, SW8, SW9, SW10, SW11, SW12, SW13, SW14, SW15, SW16: B3F-1055; B3F1000; Mouser Part Number 653-B3F-1055

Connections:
+3V3: R18.2, R19.2, R20.2, R21.2, R22.2, R23.2, R24.2, R25.2, R26.2, R44.2, R50.2, R51.2, R52.2, R53.2, R54.2, R65.2; also elsewhere on the board
GND: SW1.2 (B), SW2.2 (B), SW3.2 (B), SW4.2 (B), SW5.2 (B), SW6.2 (B), SW7.2 (B), SW8.2 (B), SW9.2 (B), SW10.2 (B), SW11.2 (B), SW12.2 (B), SW13.2 (B), SW14.2 (B), SW15.2 (B), SW16.2 (B); also elsewhere on the board
SW1: R18.1, SW1.1 (A); also elsewhere on the board
SW2: R19.1, SW2.1 (A); also elsewhere on the board
SW3: R20.1, SW3.1 (A); also elsewhere on the board
SW4: R21.1, SW4.1 (A); also elsewhere on the board
SW5: R22.1, SW5.1 (A); also elsewhere on the board
SW6: R23.1, SW6.1 (A); also elsewhere on the board
SW7: R24.1, SW7.1 (A); also elsewhere on the board
SW8: R25.1, SW8.1 (A); also elsewhere on the board
SW9: R26.1, SW9.1 (A); also elsewhere on the board
SW10: R44.1, SW10.1 (A); also elsewhere on the board
SW11: R50.1, SW11.1 (A); also elsewhere on the board
SW12: R51.1, SW12.1 (A); also elsewhere on the board
SW13: R52.1, SW13.1 (A); also elsewhere on the board
SW14: R53.1, SW14.1 (A); also elsewhere on the board
SW15: R54.1, SW15.1 (A); also elsewhere on the board
SW16: R65.1, SW16.1 (A); also elsewhere on the board

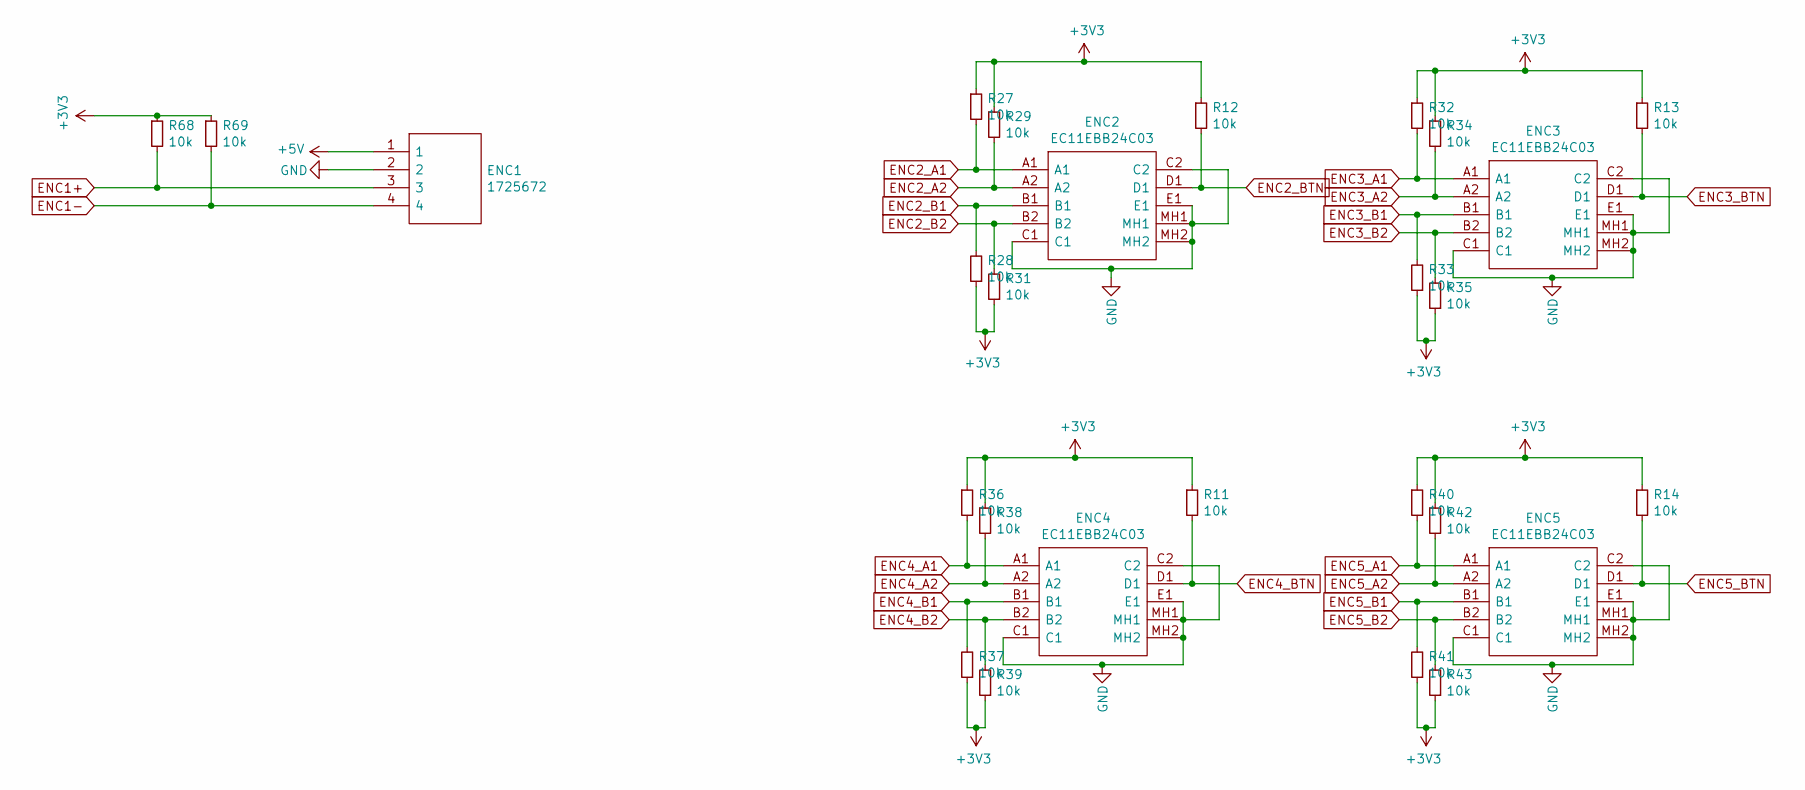
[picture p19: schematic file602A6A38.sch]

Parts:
ENC1: 1725672; 1725672-4-2.54; Mouser Part Number 651-1725672
ENC2, ENC3, ENC4, ENC5: EC11EBB24C03; Mouser Part Number 688-EC11EBB24C03
R11, R12, R13, R14, R27, R28, R29, R31, R32, R33, R34, R35, R36, R37, R38, R39, R40, R41, R42, R43, R68, R69: 10k; R_0805_2012Metric_Pad1.15x1.40mm_HandSolder; Manufacturer_Part_Number CRCW080510K0FKEAC; LCSC C17414

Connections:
+3V3: R11.1, R12.1, R13.1, R14.1, R27.1, R28.1, R29.1, R31.1, R32.1, R33.1, R34.1, R35.1, R36.1, R37.1, R38.1, R39.1, R40.1, R41.1, R42.1, R43.1, R68.1, R69.1; also elsewhere on the board
+5V: ENC1.1; also elsewhere on the board
ENC1+: ENC1.3, R68.2; also elsewhere on the board
ENC1-: ENC1.4, R69.2; also elsewhere on the board
ENC2_A1: ENC2.A1, R27.2; also elsewhere on the board
ENC2_A2: ENC2.A2, R29.2; also elsewhere on the board
ENC2_B1: ENC2.B1, R28.2; also elsewhere on the board
ENC2_B2: ENC2.B2, R31.2; also elsewhere on the board
ENC2_BTN: ENC2.D1, R12.2; also elsewhere on the board
ENC3_A1: ENC3.A1, R32.2; also elsewhere on the board
ENC3_A2: ENC3.A2, R34.2; also elsewhere on the board
ENC3_B1: ENC3.B1, R33.2; also elsewhere on the board
ENC3_B2: ENC3.B2, R35.2; also elsewhere on the board
ENC3_BTN: ENC3.D1, R13.2; also elsewhere on the board
ENC4_A1: ENC4.A1, R36.2; also elsewhere on the board
ENC4_A2: ENC4.A2, R38.2; also elsewhere on the board
ENC4_B1: ENC4.B1, R37.2; also elsewhere on the board
ENC4_B2: ENC4.B2, R39.2; also elsewhere on the board
ENC4_BTN: ENC4.D1, R11.2; also elsewhere on the board
ENC5_A1: ENC5.A1, R40.2; also elsewhere on the board
ENC5_A2: ENC5.A2, R42.2; also elsewhere on the board
ENC5_B1: ENC5.B1, R41.2; also elsewhere on the board
ENC5_B2: ENC5.B2, R43.2; also elsewhere on the board
ENC5_BTN: ENC5.D1, R14.2; also elsewhere on the board
GND: ENC1.2, ENC2.C1, ENC2.C2, ENC2.E1, ENC2.MH1, ENC2.MH2, ENC3.C1, ENC3.C2, ENC3.E1, ENC3.MH1, ENC3.MH2, ENC4.C1, ENC4.C2, ENC4.E1, ENC4.MH1, ENC4.MH2, ENC5.C1, ENC5.C2, ENC5.E1, ENC5.MH1, ENC5.MH2; also elsewhere on the board

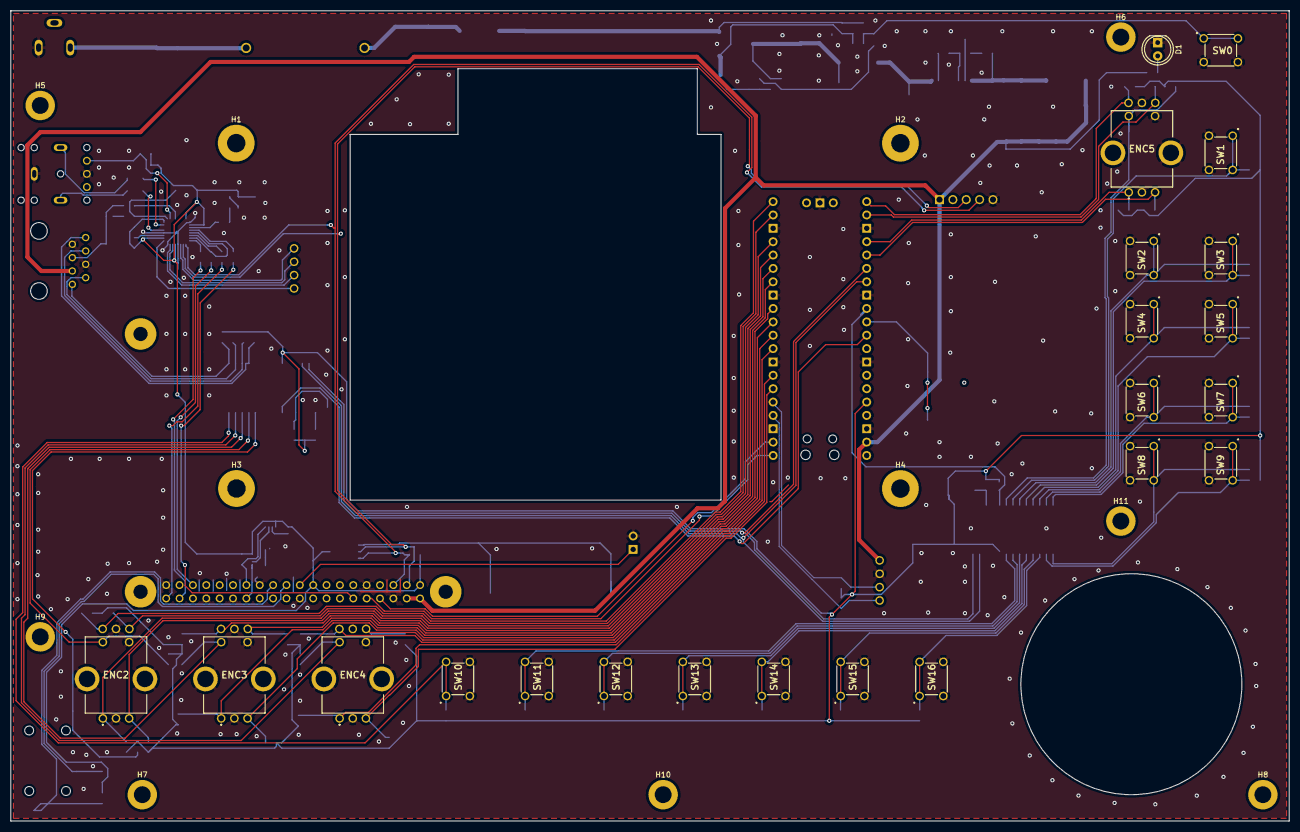
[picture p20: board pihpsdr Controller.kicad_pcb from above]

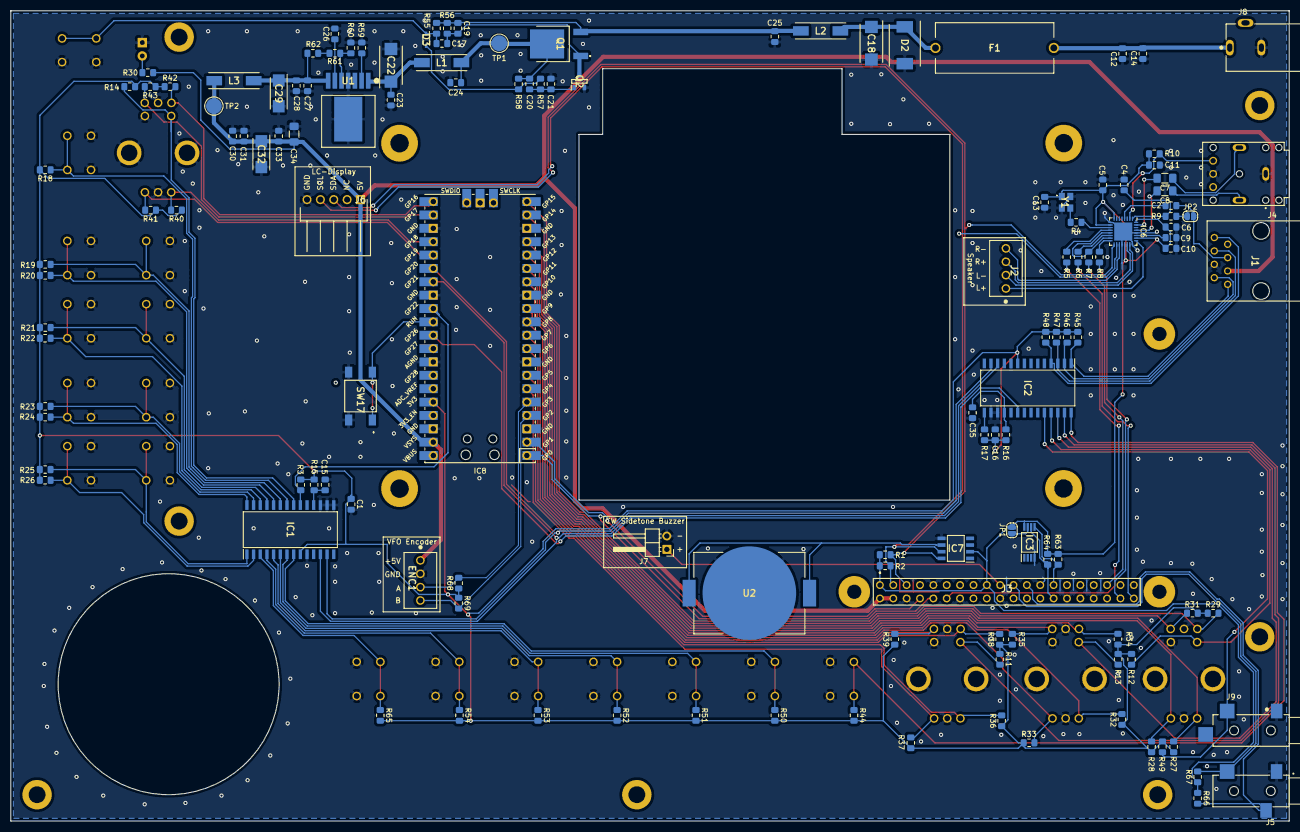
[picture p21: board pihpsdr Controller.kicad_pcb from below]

Board: 2 copper layers, 243.0 x 154.0 mm, 168 parts (135 on the bottom side), 105 nets.

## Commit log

2021-02-13 Inital checking. Still working on routing.
    [file601C1F64.sch, file601C9AC8.sch, file60264D60.sch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]
2021-02-13 Reorganized KiCad project
    [Left.stp, pihpsdr Controller.kicad_pcb]
2021-02-17 Cleaned up repository. Created a BOM in iBOM Format.
    [Button_Cap.FCStd, Left.stp, file601C1F64.sch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]
2021-02-17 recreated BOM file.
    [pihpsdr Controller.kicad_pcb]
2021-02-18 Completed parts details on schematics and recreated gerbers and bom.
    [file601C1F64.sch, file601C9AC8.sch, file60264D60.sch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]
2021-02-20 Replaced RMS20 encoder with Chinese encoder. Maybe a modification of the encoder is necessary due to internal 7805 voltage regulator.
    [Button_Cap.FCStd, Button_Cap_Power.FCStd, file602A6A38.sch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]
2021-02-20 Refactored JLC Part Numbers. And replaced 100uF capacitors with 1206 sized parts.
    [file601C1F64.sch, file601C9AC8.sch, file60264D60.sch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]
2021-02-22 Added second case variant without extruded profiles.
2021-02-23 Added Reset Button to Pi Pico to make updating firmware easier.
    [pihpsdr Controller-B_Cu.gbr, pihpsdr Controller-B_Mask.gbr, pihpsdr Controller-B_Paste.gbr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]
2021-02-23 Optimized case model and added supporting parts like Nuts, bolts and screws.
    [Front for bent metal sheet.stp]
2021-03-07 Recreated some parts
    [pihpsdr Controller-B_Cu.gbr, pihpsdr Controller-B_Mask.gbr, pihpsdr Controller-B_Paste.gbr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]
2021-03-13 Updated button caps and frontpanel layout.
    [Button_Cap.FCStd, Button_Cap_Power.FCStd]
